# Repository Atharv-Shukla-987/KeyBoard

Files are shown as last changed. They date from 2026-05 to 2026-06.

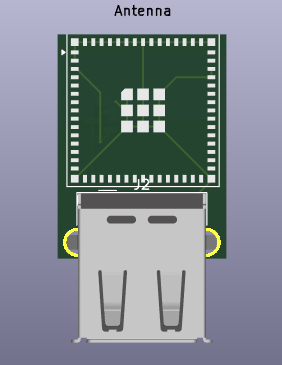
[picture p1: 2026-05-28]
img/reciever_3d_front.png

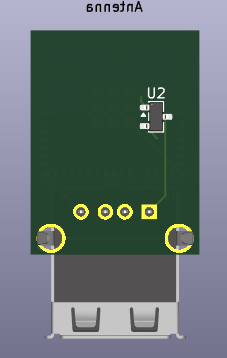
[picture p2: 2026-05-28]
img/reciever_3d_back.png

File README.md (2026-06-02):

# mech_board
## Introduction
It is compact wireless custum mechanical keyboard based on rasberry pi pico w with a 0.96 Oled display for displaying battery percentage and with a slider[linear potential meter] for music control and some DJ vibes, yes a slider not a rotary encoder because for some reason i just don't like rotary encoders. It has battery of 2000 mah . It can act as wired and wireless keyboard , both . I have a slider switch for changing the mode . It got two holes on its case wall one for charging port and other for pico port . I have also used RGBs for some asthetics. My pc does not have in built blutooth so , I have also made a reciever dougle.
## Components Used
### kerboard
 1.I have used raspberry pi pico w over others because beacause of high number of gpio pins and is easily programable and also is bluetooth and wifi for good contectivity
 2. A TP4050 [charging module] for charging battery
 
 3. A mcp1700 [voltage regulator] for converting 3.7v from battery to 5v requried from raspberry pi pico w
 
 4.A 1N4148 Diode so that ghosting do not occurs 

 5. A oled display 128x64 i2c for checking battery and making keyboard more intresting

 6. A SK6812 MINI for lightening and vibe

 7. A female Usb type C for charging 

 8. A 3.7V 2000mah lipo battery for increased battery life

 9. keycaps from meckeys

 10. custum pcb
 
 11. 3d printed case
 
 12. cherry x switches
 
 13. Capacitors and registors 

### reciever 

1.esp32 mini s3 for conecting with keyboard 

2. USb type A

3. MCP1700 voltage regulator

# RECIEVER

## schematics



## PCB layout

reciever_pcb

## 3d

### Front



### Back



# KEYBOARD

## schematic

keyboard_schematics

## PCB layout

keyboard_pcb_layout

## 3D 
### front



### back Model



## footprints







## Case

### Top case

Case_top

### Bottom case

Case_bottom

### Assembled case

Assembly

# BOM 

https://docs.google.com/spreadsheets/d/1NN-7fyjT-_NMtKUpMZtBps8UBcZRbg7seoi4lXChdCc/edit?usp=sharing


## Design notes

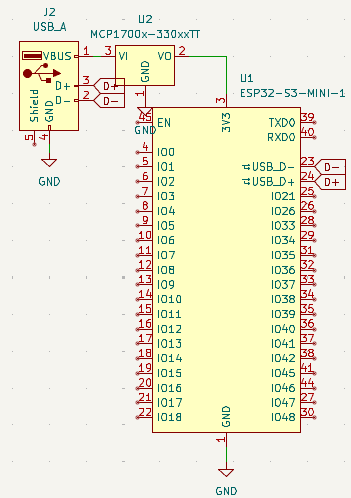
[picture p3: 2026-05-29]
img/reciever_schematics.png

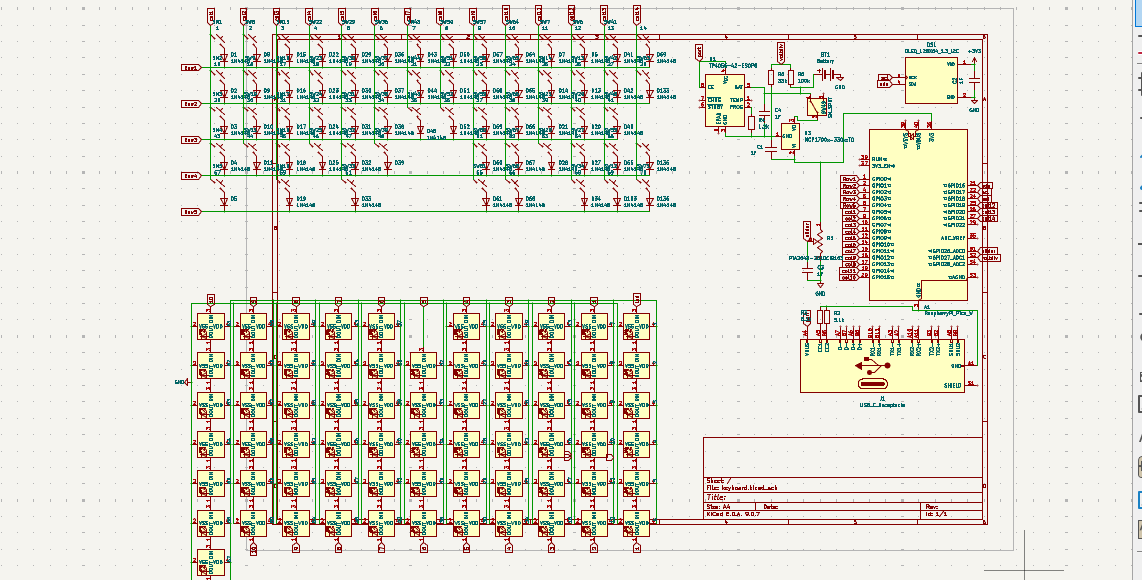
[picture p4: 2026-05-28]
img/keyboard_schematics.png

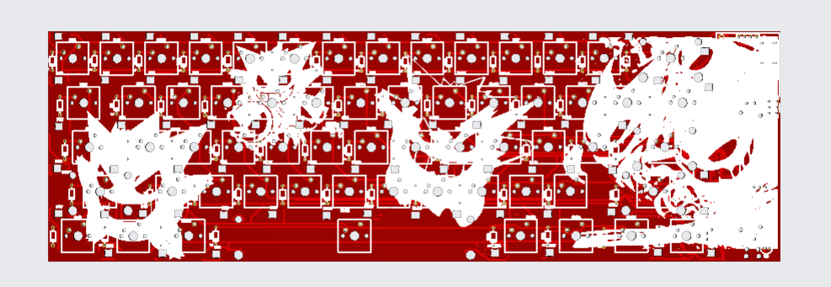
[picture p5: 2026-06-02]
img/keyboard_3d_front.png

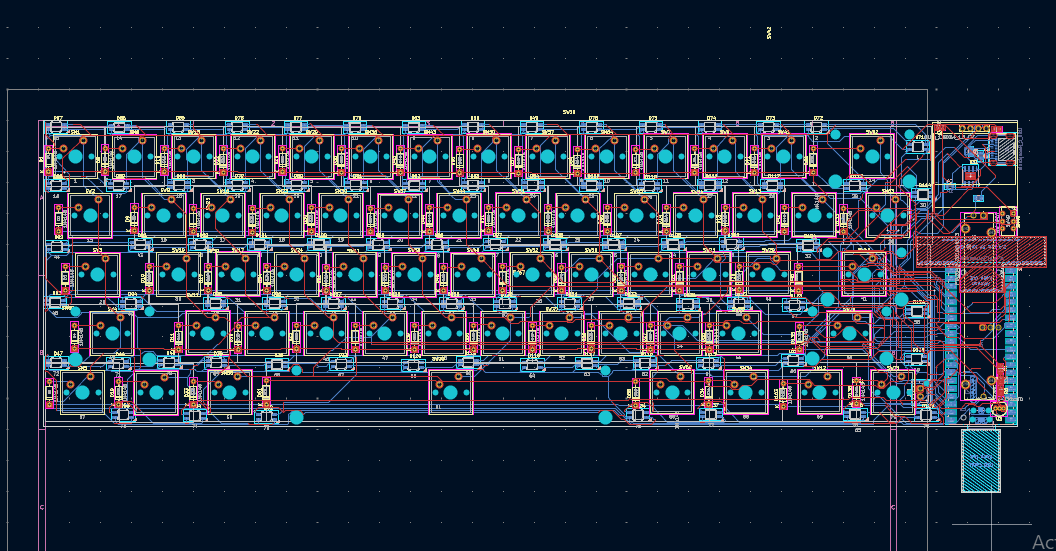
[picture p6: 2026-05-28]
img/keyboard_pcb_layout.png

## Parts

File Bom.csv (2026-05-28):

Item | Quantity | Cost per piece | Total Cost ( IN INR) | Cost in Usd( 1usd =95.23) | link
1N4148 Diode | 100 | 2 rupees | 200 | 2.1 usd | https://www.amazon.in/Embeddinator-1N4148-Diode-Pack-50/dp/B0B53NV1QC
SK6812 MINI | 200 |  | 1423 | 15usd | https://www.desertcart.in/products/792826292-200pcs-sk6812-mini-e-rgb-similar-ws2812b-sk6812-3228-smd
Rasberrypi pico w + RESISTORS (100K,33K,1.2K,5.1L) | 1 | 900 | ₹869.07 | 9 usd | https://photos.app.goo.gl/kQwkpoZnvVd7d1E5A
Battery 3.7 V | 1 | 1 | 200 | 2.1 usd | https://roboman.in/product/704060-3-7v-2000mah-lipo-battery-rechargeable-lithium-polymer-battery-with-bms/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
tp4056 | 1 | 40 | 40 | 0.5 usd | https://evelta.com/tp4056x-42-esop8-lithium-ion-battery-management-1a-ic-sop-8-ep/?sku=129-TP4056X-42-ESOP8
mcp1700 | 1 | 60 | 60 | 0.64usd | https://robu.in/product/mcp1700-3302e-to-microchip-fixed-ldo-voltage-regulator-2-3v-to-6v-to-92-3/
Akko Creamy Cyan Switch (Pack of 45) | 2 | 1299 | 2598 | 27.3 usd | https://stackskb.com/store/akko-creamy-cyan-switch-pack-of-45-pre-order/
esp32 mini s3 | 1 | 242 | 404 | 4.2 USD | https://www.lioncircuits.com/parts/ESP32-C3-MINI-1-N4-A
usb type A male ( pack of 10) | 1 | 130 | 130 | 1.36 usd | https://www.amazon.in/ICSTORE-4-Pin-Solder-Connector-Degree/dp/B0BQ7JFZDF/521-4557262-6496425
usb type C female ( pack of 5) | 1 | 100 | 100 | 1.05 USD | https://www.amazon.in/UNIVERSAL-HUB-Type-C-Connector-Breakout/dp/B0DYJMNZM1
oled display 128x64 i2c | 1 | 315 | 315 | 3.3 usd | https://www.amazon.in/IDUINO-SSD1306-Self-Luminous-Display-Raspberry/dp/B0BNWC7X54
capacitor 1 uf(pack of 10) | 1 | 99 | 99 | 1.05 usd | https://www.amazon.in/AVS-COMPONENTS-Aluminium-Electrolytic-Capacitor/dp/B08P5JX8YK?s=industrial
keycaps | 1 | 1399 | 1399 | 14.7 Usd | https://meckeys.com/shop/accessories/keyboard-accessories/keycaps/gengar-anime-keycap-set/
pcb | 5 | 800 | 5000 | 52.5usd
4mm SPDT 1P2T Slide Switch – PCB Mount Switch |  |  |  |  | https://techtonics.in/product/4mm-spdt-1p2t-slide-switch-pack-of-10/
slider [ liner potentialmeter] | 1 | 128 | 218 | 2.29usd | https://robomart.com/product/pta4543-2015dpb103-bourns/
3d printing |  |  | 300 | 3.16usd
stablizer set(4+1) | 1 | 1098 | 1098 | 11.6usd | https://www.keebsmod.com/products/cherry-clip-in-stabilizers?variant=50380987007274&country=IN&currency=INR
total |  |  | 14453 | 152.5 usd

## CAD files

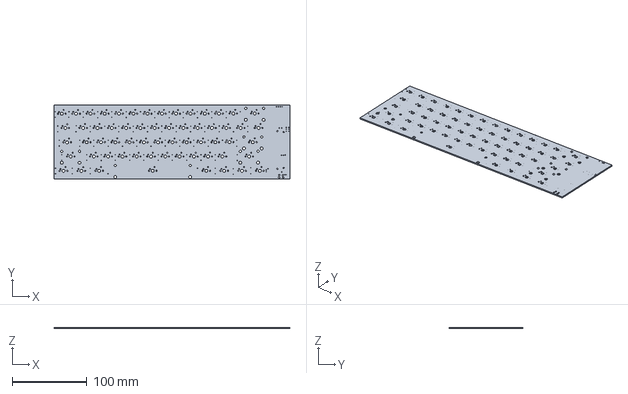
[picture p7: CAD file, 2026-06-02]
cad/keyboard_pcb.step
314.8 x 99.0 x 1.60 mm

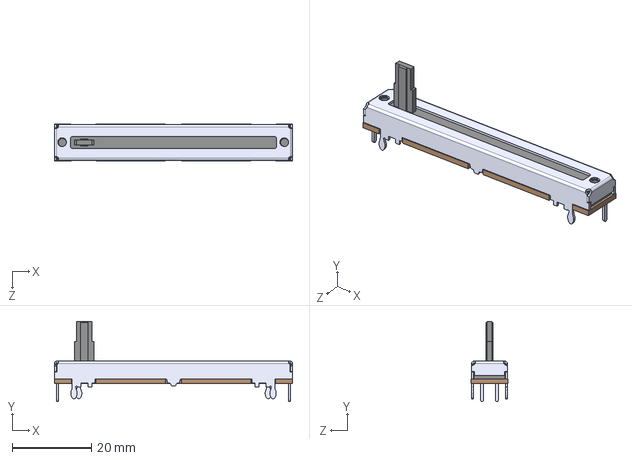
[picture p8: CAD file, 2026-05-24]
PTA4543-2010CPB103/PTA4543-2010CPB103.step
60.0 x 20.2 x 9.40 mm

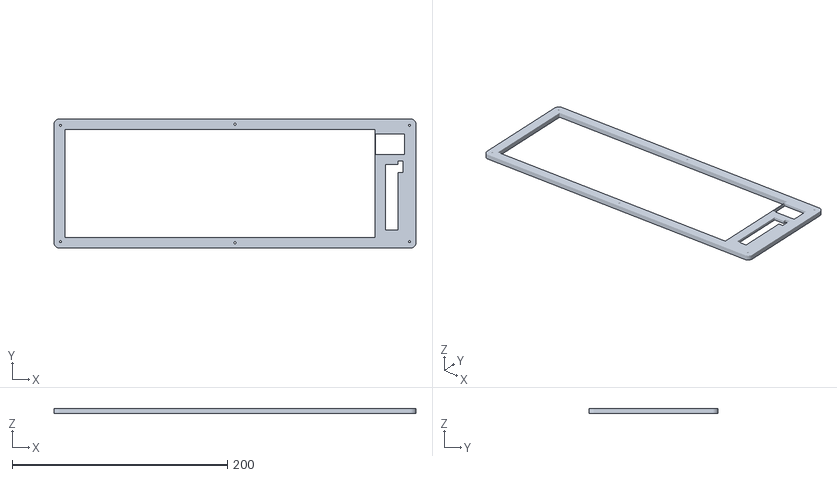
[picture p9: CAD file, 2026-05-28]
cad/keeb_top.stl
336.0 x 120.0 x 5.00

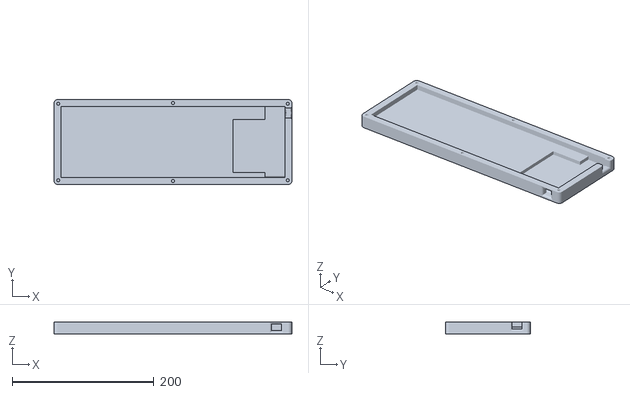
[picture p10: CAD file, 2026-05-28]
cad/keeb_bottom.stl
336.0 x 120.0 x 17.0

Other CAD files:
cad/keeb_bottom.f3z
cad/keeb_top.f3d

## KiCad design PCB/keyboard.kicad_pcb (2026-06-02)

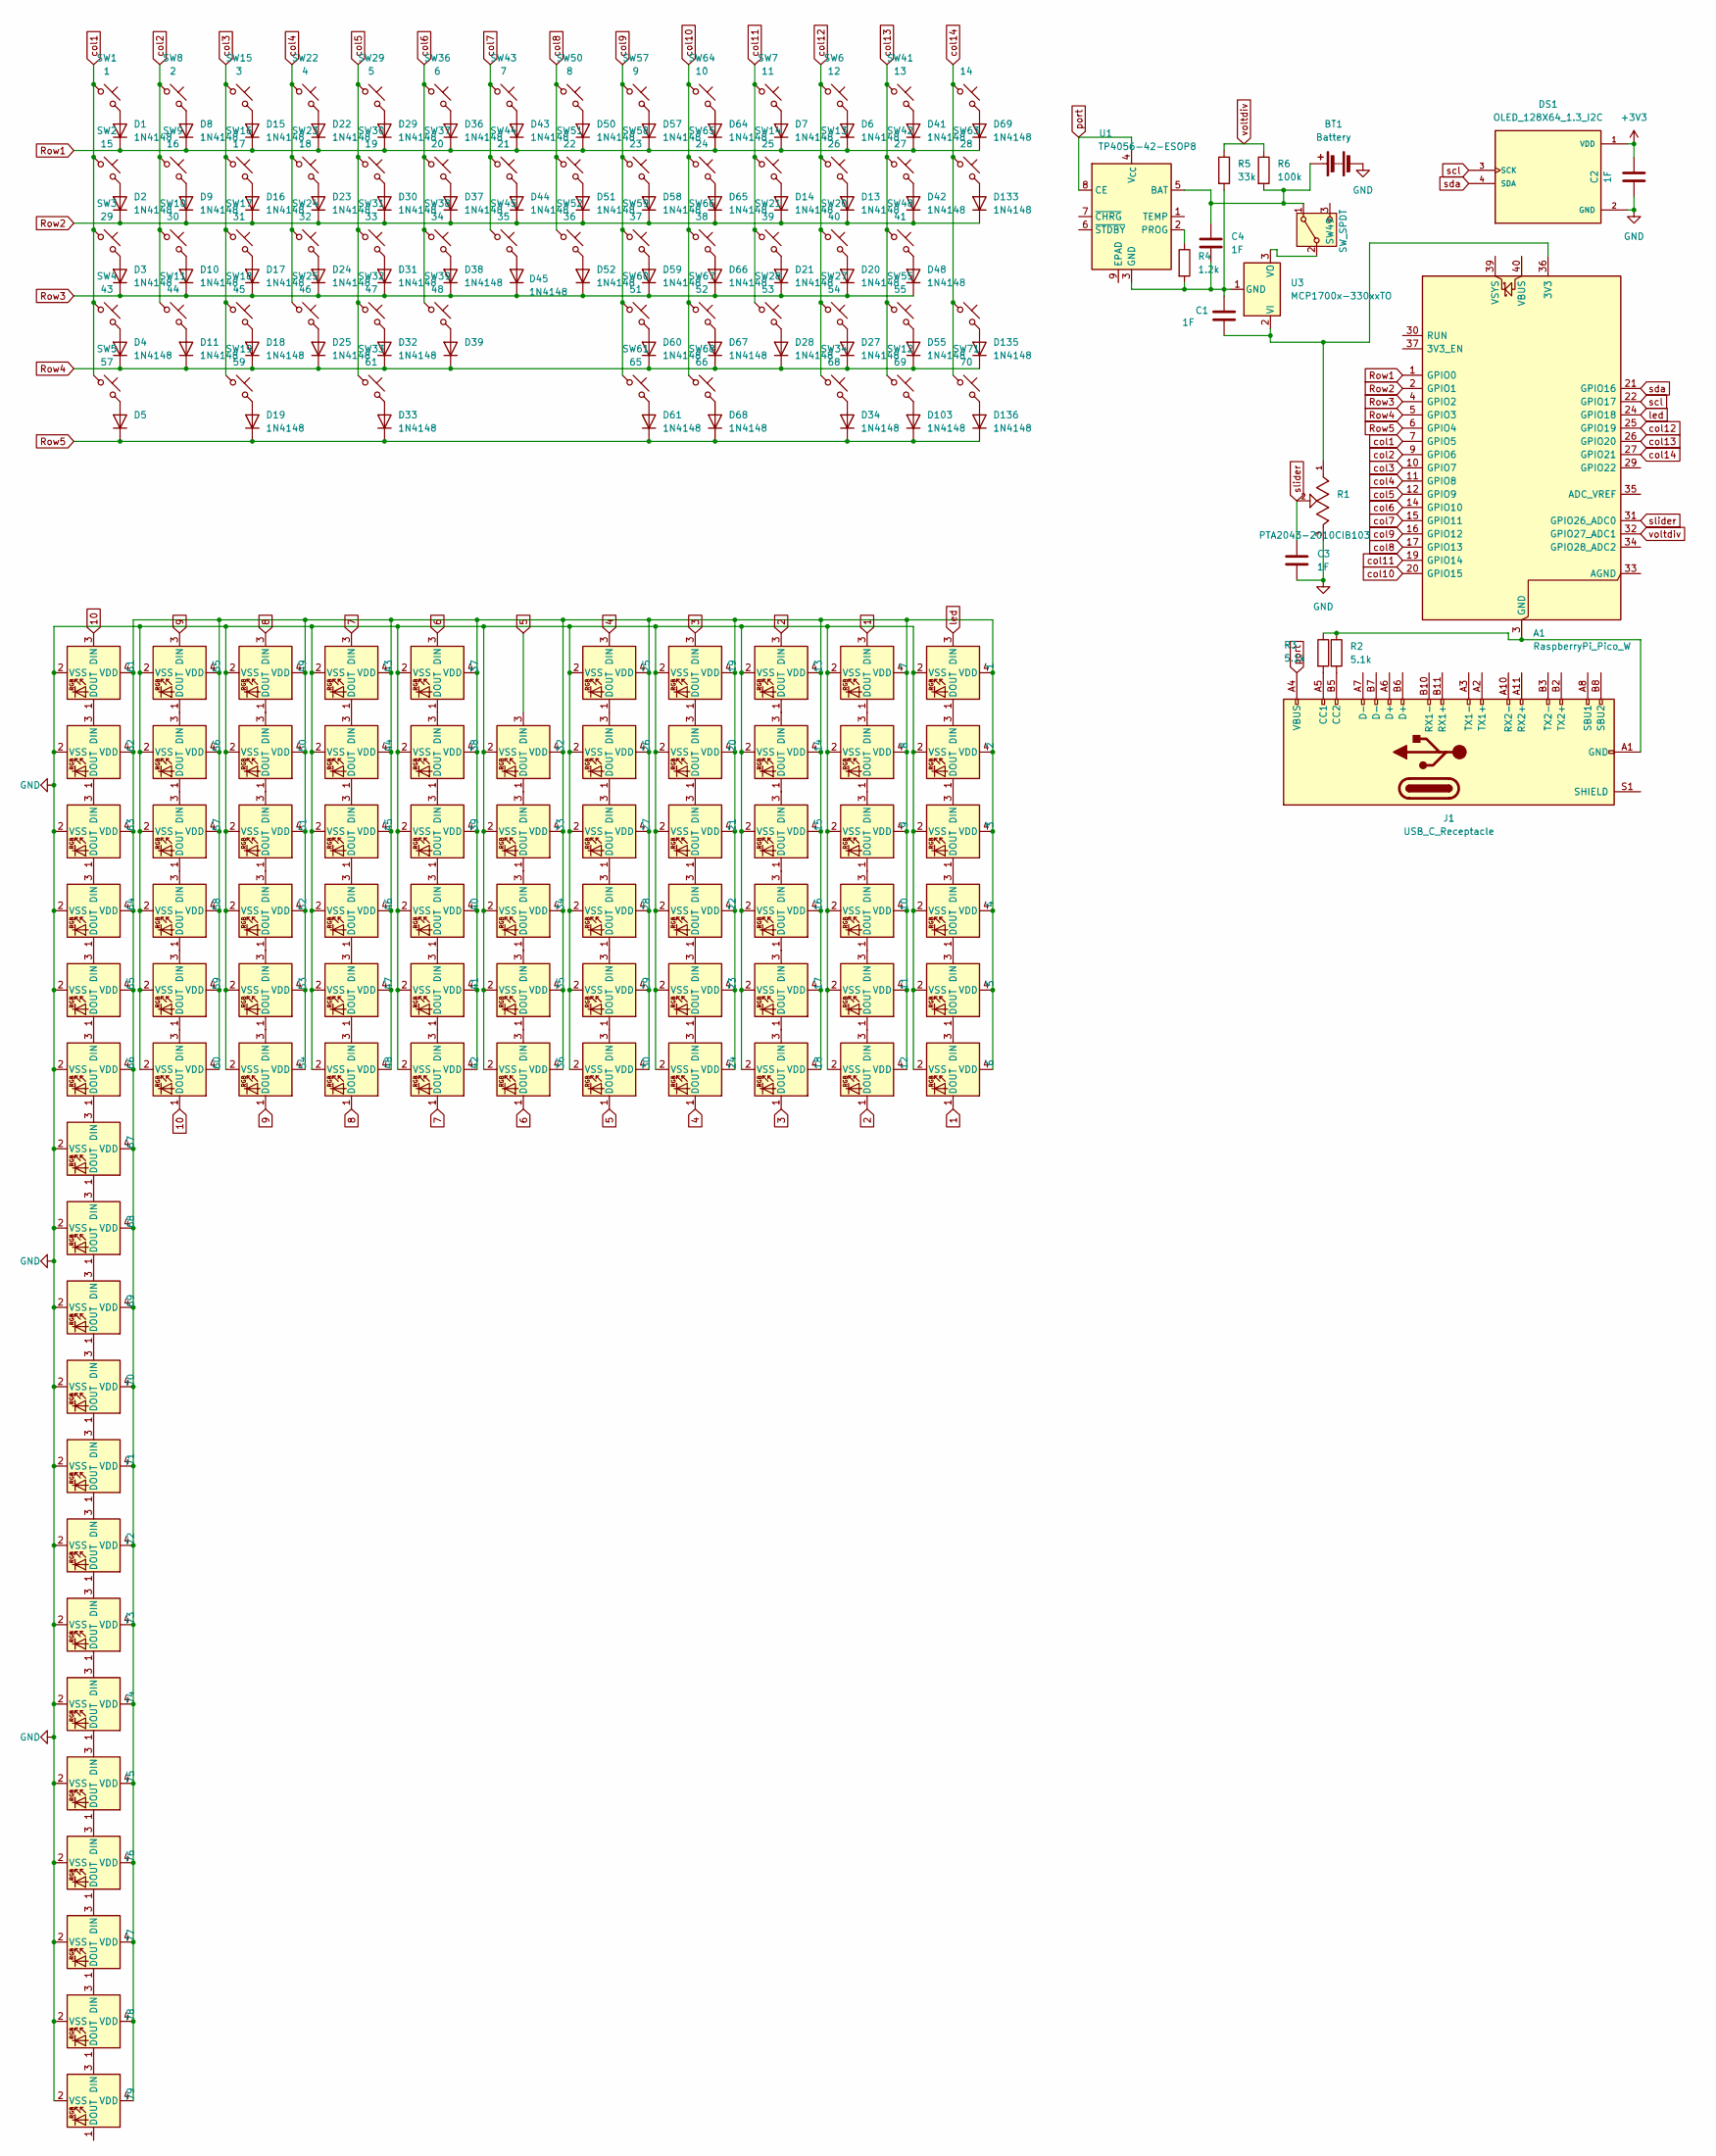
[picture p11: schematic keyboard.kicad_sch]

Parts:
A1: RaspberryPi_Pico_W; RaspberryPi_Pico_W_SMD_HandSolder
BT1: Battery; JST_XH_B2B-XH-AM_1x02_P2.50mm_Vertical
C1, C2, C3, C4: 1F; C_0805_2012Metric
D1, D2, D3, D4, D5, D6, D7, D8, D9, D10, D11, D13, D14, D15, D16, D17, D18, D19, D20, D21, D22, D23, D24, D25, D27, D28, D29, D30, D31, D32, D33, D34, D36, D37, D38, D39, D41, D42, D43, D44, D45, D48, D50, D51, D52, D55, D57, D58, D59, D60, D61, D64, D65, D66, D67, D68, D69, D103, D133, D135, D136: 1N4148; D_DO-35_SOD27_P7.62mm_Horizontal
D12: 67; SK6812MINI-E_fixed
D26: 68; SK6812MINI-E_fixed
D35: 69; SK6812MINI-E_fixed
D40: 70; SK6812MINI-E_fixed
D46: 71; SK6812MINI-E_fixed
D47: 72; SK6812MINI-E_fixed
D49: 7; SK6812MINI-E_fixed
D53: 73; SK6812MINI-E_fixed
D54: 74; SK6812MINI-E_fixed
D56: 8; SK6812MINI-E_fixed
D62: 75; SK6812MINI-E_fixed
D63: 9; SK6812MINI-E_fixed
D70: 10; SK6812MINI-E_fixed
D71: 1; SK6812MINI-E_fixed
D72: 2; SK6812MINI-E_fixed
D73: 3; SK6812MINI-E_fixed
D74: 4; SK6812MINI-E_fixed
D75: 5; SK6812MINI-E_fixed
D76: 6; SK6812MINI-E_fixed
D77: 11; SK6812MINI-E_fixed
D78: 12; SK6812MINI-E_fixed
D79: 19; SK6812MINI-E_fixed
D80: 20; SK6812MINI-E_fixed
D81: 21; SK6812MINI-E_fixed
D82: 22; SK6812MINI-E_fixed
D83: 23; SK6812MINI-E_fixed
D84: 24; SK6812MINI-E_fixed
D85: 13; SK6812MINI-E_fixed
D86: 14; SK6812MINI-E_fixed
D87: 15; SK6812MINI-E_fixed
D88: 16; SK6812MINI-E_fixed
D89: 17; SK6812MINI-E_fixed
D90: 18; SK6812MINI-E_fixed
D91: 43; SK6812MINI-E_fixed
D92: 44; SK6812MINI-E_fixed
D93: 45; SK6812MINI-E_fixed
D94: 46; SK6812MINI-E_fixed
D95: 47; SK6812MINI-E_fixed
D96: 48; SK6812MINI-E_fixed
D97: 37; SK6812MINI-E_fixed
D98: 38; SK6812MINI-E_fixed
D99: 39; SK6812MINI-E_fixed
D100: 40; SK6812MINI-E_fixed
D101: 41; SK6812MINI-E_fixed
D102: 42; SK6812MINI-E_fixed
D104: 32; SK6812MINI-E_fixed
D105: 33; SK6812MINI-E_fixed
D106: 34; SK6812MINI-E_fixed
D107: 35; SK6812MINI-E_fixed
D108: 36; SK6812MINI-E_fixed
D109: 25; SK6812MINI-E_fixed
D110: 26; SK6812MINI-E_fixed
D111: 27; SK6812MINI-E_fixed
D112: 28; SK6812MINI-E_fixed
D113: 29; SK6812MINI-E_fixed
D114: 30; SK6812MINI-E_fixed
D115: 61; SK6812MINI-E_fixed
D116: 62; SK6812MINI-E_fixed
D117: 63; SK6812MINI-E_fixed
D118: 64; SK6812MINI-E_fixed
D119: 65; SK6812MINI-E_fixed
D120: 66; SK6812MINI-E_fixed
D121: 55; SK6812MINI-E_fixed
D122: 56; SK6812MINI-E_fixed
D123: 57; SK6812MINI-E_fixed
D124: 58; SK6812MINI-E_fixed
D125: 59; SK6812MINI-E_fixed
D126: 60; SK6812MINI-E_fixed
D127: 49; SK6812MINI-E_fixed
D128: 50; SK6812MINI-E_fixed
D129: 51; SK6812MINI-E_fixed
D130: 52; SK6812MINI-E_fixed
D131: 53; SK6812MINI-E_fixed
D132: 54; SK6812MINI-E_fixed
D134: 76; SK6812MINI-E_fixed
D137: 77; SK6812MINI-E_fixed
D138: 78; SK6812MINI-E_fixed
D139: 79; SK6812MINI-E_fixed
DS1: OLED_128X64_1.3_I2C; LCD_OLED_128X64_1.3_I2C; PARTREV NA
J1: USB_C_Receptacle; USB_C_Receptacle_Molex_105450-0101
R1: PTA2043-2010CIB103; TRIM_PTA4543-2010CPB103; PARTREV 04/21
R2, R3: 5.1k; R_0805_2012Metric
R4: 1.2k; R_0805_2012Metric
R5: 33k; R_0805_2012Metric
R6: 100k; R_0805_2012Metric
SW1: 1; SW_Cherry_MX1A_1.00u_PCB
SW2: 15; SW_Cherry_MX1A_1.50u_PCB
SW3: 29; SW_Cherry_MX1A_1.75u_PCB
SW4: 43; SW_Cherry_MX1A_2.25u_PCB
SW5: 57; SW_Cherry_MX1A_1.25u_PCB
SW6: 12; SW_Cherry_MX1A_1.00u_PCB
SW7: 11; SW_Cherry_MX1A_1.00u_PCB
SW8: 2; SW_Cherry_MX1A_1.00u_PCB
SW9: 16; SW_Cherry_MX1A_1.00u_PCB
SW10: 30; SW_Cherry_MX1A_1.00u_PCB
SW11: 44; SW_Cherry_MX1A_1.00u_PCB
SW12: 69; SW_Cherry_MX1A_1.25u_PCB
SW13: 26; SW_Cherry_MX1A_1.00u_PCB
SW14: 25; SW_Cherry_MX1A_1.00u_PCB
SW15: 3; SW_Cherry_MX1A_1.00u_PCB
SW16: 17; SW_Cherry_MX1A_1.00u_PCB
SW17: 31; SW_Cherry_MX1A_1.00u_PCB
SW18: 45; SW_Cherry_MX1A_1.00u_PCB
SW19: 59; SW_Cherry_MX1A_1.25u_PCB
SW20: 40; SW_Cherry_MX1A_1.00u_PCB
SW21: 39; SW_Cherry_MX1A_1.00u_PCB
SW22: 4; SW_Cherry_MX1A_1.00u_PCB
SW23: 18; SW_Cherry_MX1A_1.00u_PCB
SW24: 32; SW_Cherry_MX1A_1.00u_PCB
SW25: 46; SW_Cherry_MX1A_1.00u_PCB
SW27: 54; SW_Cherry_MX1A_1.00u_PCB
SW28: 53; SW_Cherry_MX1A_1.00u_PCB
SW29: 5; SW_Cherry_MX1A_1.00u_PCB
SW30: 19; SW_Cherry_MX1A_1.00u_PCB
SW31: 33; SW_Cherry_MX1A_1.00u_PCB
SW32: 47; SW_Cherry_MX1A_1.00u_PCB
SW33: 61; SW_Cherry_MX1A_1.25u_PCB
SW34: 68; SW_Cherry_MX1A_1.25u_PCB
SW36: 6; SW_Cherry_MX1A_1.00u_PCB
SW37: 20; SW_Cherry_MX1A_1.00u_PCB
SW38: 34; SW_Cherry_MX1A_1.00u_PCB
SW39: 48; SW_Cherry_MX1A_1.00u_PCB
SW41: 13; SW_Cherry_MX1A_1.00u_PCB
SW42: 27; SW_Cherry_MX1A_1.00u_PCB
SW43: 7; SW_Cherry_MX1A_1.00u_PCB
SW44: 21; SW_Cherry_MX1A_1.00u_PCB
SW45: 35; SW_Cherry_MX1A_1.00u_PCB
SW48: 41; SW_Cherry_MX1A_2.25u_PCB
SW49: SW_SPDT; SW_Slide_1P2T_CK_OS102011MS2Q
SW50: 8; SW_Cherry_MX1A_1.00u_PCB
SW51: 22; SW_Cherry_MX1A_1.00u_PCB
SW52: 36; SW_Cherry_MX1A_1.00u_PCB
SW55: 55; SW_Cherry_MX1A_1.00u_PCB
SW57: 9; SW_Cherry_MX1A_1.00u_PCB
SW58: 23; SW_Cherry_MX1A_1.00u_PCB
SW59: 37; SW_Cherry_MX1A_1.00u_PCB
SW60: 51; SW_Cherry_MX1A_1.00u_PCB
SW61: 65; SW_Cherry_MX1A_6.25u_PCB
SW62: 14; SW_Cherry_MX1A_2.00u_PCB
SW63: 28; SW_Cherry_MX1A_1.50u_PCB
SW64: 10; SW_Cherry_MX1A_1.00u_PCB
SW65: 24; SW_Cherry_MX1A_1.00u_PCB
SW66: 38; SW_Cherry_MX1A_1.00u_PCB
SW67: 52; SW_Cherry_MX1A_1.00u_PCB
SW68: 66; SW_Cherry_MX1A_1.25u_PCB
SW70: 56; SW_Cherry_MX1A_2.75u_PCB
SW71: 70; SW_Cherry_MX1A_1.25u_PCB
U1: TP4056-42-ESOP8; SOIC-8-1EP_3.9x4.9mm_P1.27mm_EP2.41x3.3mm_ThermalVias
U3: MCP1700x-330xxTO; TO-92_Inline

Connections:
1: D49.3 (DIN), D76.1 (DOUT)
2: D78.1 (DOUT), D85.3 (DIN)
3: D79.3 (DIN), D90.1 (DOUT)
4: D84.1 (DOUT), D109.3 (DIN)
5: D104.3 (DIN), D114.1 (DOUT)
6: D97.3 (DIN), D108.1 (DOUT)
7: D91.3 (DIN), D102.1 (DOUT)
8: D96.1 (DOUT), D127.3 (DIN)
9: D121.3 (DIN), D132.1 (DOUT)
10: D115.3 (DIN), D126.1 (DOUT)
+3V3: C2.1, DS1.1 (VDD)
<NO NET>: D12.4 (VDD), D26.4 (VDD), D35.4 (VDD), D40.4 (VDD), D46.4 (VDD), D47.4 (VDD), D49.4 (VDD), D53.4 (VDD), D54.4 (VDD), D56.4 (VDD), D62.4 (VDD), D63.4 (VDD), D70.4 (VDD), D71.4 (VDD), D72.4 (VDD), D73.4 (VDD), D74.4 (VDD), D75.4 (VDD), D76.4 (VDD), D77.4 (VDD), D78.4 (VDD), D79.4 (VDD), D80.4 (VDD), D81.4 (VDD), D82.4 (VDD), D83.4 (VDD), D84.4 (VDD), D85.4 (VDD), D86.4 (VDD), D87.4 (VDD), D88.4 (VDD), D89.4 (VDD), D90.4 (VDD), D91.4 (VDD), D92.4 (VDD), D93.4 (VDD), D94.4 (VDD), D95.4 (VDD), D96.4 (VDD), D97.4 (VDD), D98.4 (VDD), D99.4 (VDD), D100.4 (VDD), D101.4 (VDD), D102.4 (VDD), D104.4 (VDD), D105.4 (VDD), D106.4 (VDD), D107.4 (VDD), D108.4 (VDD), D109.4 (VDD), D110.4 (VDD), D111.4 (VDD), D112.4 (VDD), D113.4 (VDD), D114.4 (VDD), D115.4 (VDD), D116.4 (VDD), D117.4 (VDD), D118.4 (VDD), D119.4 (VDD), D120.4 (VDD), D121.4 (VDD), D122.4 (VDD), D123.4 (VDD), D124.4 (VDD), D125.4 (VDD), D126.4 (VDD), D127.4 (VDD), D128.4 (VDD), D129.4 (VDD), D130.4 (VDD), D131.4 (VDD), D132.4 (VDD), D134.4 (VDD), D137.4 (VDD), D138.4 (VDD), D139.4 (VDD)
GND: BT1.2 (-), C2.2, C3.2, D12.2 (VSS), D26.2 (VSS), D35.2 (VSS), D40.2 (VSS), D46.2 (VSS), D47.2 (VSS), D49.2 (VSS), D53.2 (VSS), D54.2 (VSS), D56.2 (VSS), D62.2 (VSS), D63.2 (VSS), D70.2 (VSS), D71.2 (VSS), D72.2 (VSS), D73.2 (VSS), D74.2 (VSS), D75.2 (VSS), D76.2 (VSS), D77.2 (VSS), D78.2 (VSS), D79.2 (VSS), D80.2 (VSS), D81.2 (VSS), D82.2 (VSS), D83.2 (VSS), D84.2 (VSS), D85.2 (VSS), D86.2 (VSS), D87.2 (VSS), D88.2 (VSS), D89.2 (VSS), D90.2 (VSS), D91.2 (VSS), D92.2 (VSS), D93.2 (VSS), D94.2 (VSS), D95.2 (VSS), D96.2 (VSS), D97.2 (VSS), D98.2 (VSS), D99.2 (VSS), D100.2 (VSS), D101.2 (VSS), D102.2 (VSS), D104.2 (VSS), D105.2 (VSS), D106.2 (VSS), D107.2 (VSS), D108.2 (VSS), D109.2 (VSS), D110.2 (VSS), D111.2 (VSS), D112.2 (VSS), D113.2 (VSS), D114.2 (VSS), D115.2 (VSS), D116.2 (VSS), D117.2 (VSS), D118.2 (VSS), D119.2 (VSS), D120.2 (VSS), D121.2 (VSS), D122.2 (VSS), D123.2 (VSS), D124.2 (VSS), D125.2 (VSS), D126.2 (VSS), D127.2 (VSS), D128.2 (VSS), D129.2 (VSS), D130.2 (VSS), D131.2 (VSS), D132.2 (VSS), D134.2 (VSS), D137.2 (VSS), D138.2 (VSS), D139.2 (VSS), DS1.2 (GND), R1.3
unnamed: A1.36 (3V3), C1.2, R1.1, U3.2 (VI)
unnamed: A1.3 (GND), A1.8 (GND), A1.13 (GND), A1.18 (GND), A1.23 (GND), A1.28 (GND), A1.38 (GND), J1.A1 (GND), J1.A12 (GND), J1.B1 (GND), J1.B12 (GND), R2.1, R3.1
unnamed: BT1.1 (+), C4.1, R6.2, SW49.1 (A), U1.5 (BAT)
unnamed: D1.2 (A), SW1.2
unnamed: D2.2 (A), SW2.2
unnamed: D3.2 (A), SW3.2
unnamed: D4.2 (A), SW4.2
unnamed: D5.2 (A), SW5.2
unnamed: D6.2 (A), SW6.2
unnamed: D7.2 (A), SW7.2
unnamed: D8.2 (A), SW8.2
unnamed: D9.2 (A), SW9.2
unnamed: D10.2 (A), SW10.2
unnamed: D11.2 (A), SW11.2
unnamed: D12.3 (DIN), D120.1 (DOUT)
unnamed: D12.1 (DOUT), D26.3 (DIN)
unnamed: D13.2 (A), SW13.2
unnamed: D14.2 (A), SW14.2
unnamed: D15.2 (A), SW15.2
unnamed: D16.2 (A), SW16.2
unnamed: D17.2 (A), SW17.2
unnamed: D18.2 (A), SW18.2
unnamed: D19.2 (A), SW19.2
unnamed: D20.2 (A), SW20.2
unnamed: D21.2 (A), SW21.2
unnamed: D22.2 (A), SW22.2
unnamed: D23.2 (A), SW23.2
unnamed: D24.2 (A), SW24.2
unnamed: D25.2 (A), SW25.2
unnamed: D26.1 (DOUT), D35.3 (DIN)
unnamed: D27.2 (A), SW27.2
unnamed: D28.2 (A), SW28.2
unnamed: D29.2 (A), SW29.2
unnamed: D30.2 (A), SW30.2
unnamed: D31.2 (A), SW31.2
unnamed: D32.2 (A), SW32.2
unnamed: D33.2 (A), SW33.2
unnamed: D34.2 (A), SW34.2
unnamed: D35.1 (DOUT), D40.3 (DIN)
unnamed: D36.2 (A), SW36.2
unnamed: D37.2 (A), SW37.2
unnamed: D38.2 (A), SW38.2
unnamed: D39.2 (A), SW39.2
unnamed: D40.1 (DOUT), D46.3 (DIN)
unnamed: D41.2 (A), SW41.2
unnamed: D42.2 (A), SW42.2
unnamed: D43.2 (A), SW43.2
unnamed: D44.2 (A), SW44.2
unnamed: D45.2 (A), SW45.2
unnamed: D46.1 (DOUT), D47.3 (DIN)
unnamed: D47.1 (DOUT), D53.3 (DIN)
unnamed: D48.2 (A), SW48.2
unnamed: D49.1 (DOUT), D56.3 (DIN)
unnamed: D50.2 (A), SW50.2
unnamed: D51.2 (A), SW51.2
unnamed: D52.2 (A), SW52.2
unnamed: D53.1 (DOUT), D54.3 (DIN)
unnamed: D54.1 (DOUT), D62.3 (DIN)
unnamed: D55.2 (A), SW55.2
unnamed: D56.1 (DOUT), D63.3 (DIN)
unnamed: D57.2 (A), SW57.2
unnamed: D58.2 (A), SW58.2
unnamed: D59.2 (A), SW59.2
unnamed: D60.2 (A), SW60.2
unnamed: D61.2 (A), SW61.2
unnamed: D63.1 (DOUT), D70.3 (DIN)
unnamed: D64.2 (A), SW64.2
unnamed: D65.2 (A), SW65.2
unnamed: D66.2 (A), SW66.2
unnamed: D67.2 (A), SW67.2
unnamed: D68.2 (A), SW68.2
unnamed: D69.2 (A), SW62.2
unnamed: D70.1 (DOUT), D77.3 (DIN)
unnamed: D71.1 (DOUT), D72.3 (DIN)
unnamed: D72.1 (DOUT), D73.3 (DIN)
unnamed: D73.1 (DOUT), D74.3 (DIN)
unnamed: D74.1 (DOUT), D75.3 (DIN)
unnamed: D75.1 (DOUT), D76.3 (DIN)
unnamed: D77.1 (DOUT), D78.3 (DIN)
unnamed: D79.1 (DOUT), D80.3 (DIN)
unnamed: D80.1 (DOUT), D81.3 (DIN)
unnamed: D81.1 (DOUT), D82.3 (DIN)
unnamed: D82.1 (DOUT), D83.3 (DIN)
unnamed: D83.1 (DOUT), D84.3 (DIN)
unnamed: D85.1 (DOUT), D86.3 (DIN)
unnamed: D86.1 (DOUT), D87.3 (DIN)
unnamed: D87.1 (DOUT), D88.3 (DIN)
unnamed: D88.1 (DOUT), D89.3 (DIN)
unnamed: D89.1 (DOUT), D90.3 (DIN)
unnamed: D91.1 (DOUT), D92.3 (DIN)
unnamed: D92.1 (DOUT), D93.3 (DIN)
unnamed: D93.1 (DOUT), D94.3 (DIN)
unnamed: D94.1 (DOUT), D95.3 (DIN)
unnamed: D95.1 (DOUT), D96.3 (DIN)
unnamed: D97.1 (DOUT), D98.3 (DIN)
unnamed: D98.1 (DOUT), D99.3 (DIN)
unnamed: D99.1 (DOUT), D100.3 (DIN)
unnamed: D100.1 (DOUT), D101.3 (DIN)
unnamed: D101.1 (DOUT), D102.3 (DIN)
unnamed: D103.2 (A), SW12.2
unnamed: D104.1 (DOUT), D105.3 (DIN)
unnamed: D105.1 (DOUT), D106.3 (DIN)
unnamed: D106.1 (DOUT), D107.3 (DIN)
unnamed: D107.1 (DOUT), D108.3 (DIN)
unnamed: D109.1 (DOUT), D110.3 (DIN)
unnamed: D110.1 (DOUT), D111.3 (DIN)
unnamed: D111.1 (DOUT), D112.3 (DIN)
unnamed: D112.1 (DOUT), D113.3 (DIN)
unnamed: D113.1 (DOUT), D114.3 (DIN)
unnamed: D115.1 (DOUT), D116.3 (DIN)
unnamed: D116.1 (DOUT), D117.3 (DIN)
unnamed: D117.1 (DOUT), D118.3 (DIN)
unnamed: D118.1 (DOUT), D119.3 (DIN)
unnamed: D119.1 (DOUT), D120.3 (DIN)
unnamed: D121.1 (DOUT), D122.3 (DIN)
unnamed: D122.1 (DOUT), D123.3 (DIN)
unnamed: D123.1 (DOUT), D124.3 (DIN)
unnamed: D124.1 (DOUT), D125.3 (DIN)
unnamed: D125.1 (DOUT), D126.3 (DIN)
unnamed: D127.1 (DOUT), D128.3 (DIN)
unnamed: D128.1 (DOUT), D129.3 (DIN)
unnamed: D129.1 (DOUT), D130.3 (DIN)
unnamed: D130.1 (DOUT), D131.3 (DIN)
unnamed: D131.1 (DOUT), D132.3 (DIN)
unnamed: D133.2 (A), SW63.2
unnamed: D62.1 (DOUT), D134.3 (DIN)
unnamed: D134.1 (DOUT), D137.3 (DIN)
unnamed: D135.2 (A), SW70.2
unnamed: D136.2 (A), SW71.2
unnamed: D137.1 (DOUT), D138.3 (DIN)
unnamed: D138.1 (DOUT), D139.3 (DIN)
unnamed: J1.A5 (CC1), R3.2
unnamed: J1.B5 (CC2), R2.2
unnamed: SW49.2 (B), U3.3 (VO)
unnamed: C1.1, C4.2, R4.2, R5.2, U1.3 (GND), U3.1 (GND)
unnamed: R4.1, U1.2 (PROG)
Row1: A1.1 (GPIO0), D1.1 (K), D6.1 (K), D7.1 (K), D8.1 (K), D15.1 (K), D22.1 (K), D29.1 (K), D36.1 (K), D41.1 (K), D43.1 (K), D50.1 (K), D57.1 (K), D64.1 (K), D69.1 (K)
Row2: A1.2 (GPIO1), D2.1 (K), D9.1 (K), D13.1 (K), D14.1 (K), D16.1 (K), D23.1 (K), D30.1 (K), D37.1 (K), D42.1 (K), D44.1 (K), D51.1 (K), D58.1 (K), D65.1 (K), D133.1 (K)
Row3: A1.4 (GPIO2), D3.1 (K), D10.1 (K), D17.1 (K), D20.1 (K), D21.1 (K), D24.1 (K), D31.1 (K), D38.1 (K), D45.1 (K), D48.1 (K), D52.1 (K), D59.1 (K), D66.1 (K)
Row4: A1.5 (GPIO3), D4.1 (K), D11.1 (K), D18.1 (K), D25.1 (K), D27.1 (K), D28.1 (K), D32.1 (K), D39.1 (K), D55.1 (K), D60.1 (K), D67.1 (K), D135.1 (K)
Row5: A1.6 (GPIO4), D5.1 (K), D19.1 (K), D33.1 (K), D34.1 (K), D61.1 (K), D68.1 (K), D103.1 (K), D136.1 (K)
col1: A1.7 (GPIO5), SW1.1, SW2.1, SW3.1, SW4.1, SW5.1
col2: A1.9 (GPIO6), SW8.1, SW9.1, SW10.1, SW11.1
col3: A1.10 (GPIO7), SW15.1, SW16.1, SW17.1, SW18.1, SW19.1
col4: A1.11 (GPIO8), SW22.1, SW23.1, SW24.1, SW25.1
col5: A1.12 (GPIO9), SW29.1, SW30.1, SW31.1, SW32.1, SW33.1
col6: A1.14 (GPIO10), SW36.1, SW37.1, SW38.1, SW39.1
col7: A1.15 (GPIO11), SW43.1, SW44.1, SW45.1
col8: A1.17 (GPIO13), SW50.1, SW51.1, SW52.1
col9: A1.16 (GPIO12), SW57.1, SW58.1, SW59.1, SW60.1, SW61.1
col10: A1.20 (GPIO15), SW64.1, SW65.1, SW66.1, SW67.1, SW68.1
col11: A1.19 (GPIO14), SW7.1, SW14.1, SW21.1, SW28.1
col12: A1.25 (GPIO19), SW6.1, SW13.1, SW20.1, SW27.1, SW34.1
col13: A1.26 (GPIO20), SW12.1, SW41.1, SW42.1, SW48.1, SW55.1
col14: A1.27 (GPIO21), SW62.1, SW63.1, SW70.1, SW71.1
led: A1.24 (GPIO18), D71.3 (DIN)
port: J1.A4 (VBUS), J1.A9 (VBUS), J1.B4 (VBUS), J1.B9 (VBUS), U1.4 (V_{CC}), U1.8 (CE)
scl: A1.22 (GPIO17), DS1.3 (SCK)
sda: A1.21 (GPIO16), DS1.4 (SDA)
slider: A1.31 (GPIO26_ADC0), C3.1, R1.2
voltdiv: A1.32 (GPIO27_ADC1), R5.1, R6.1

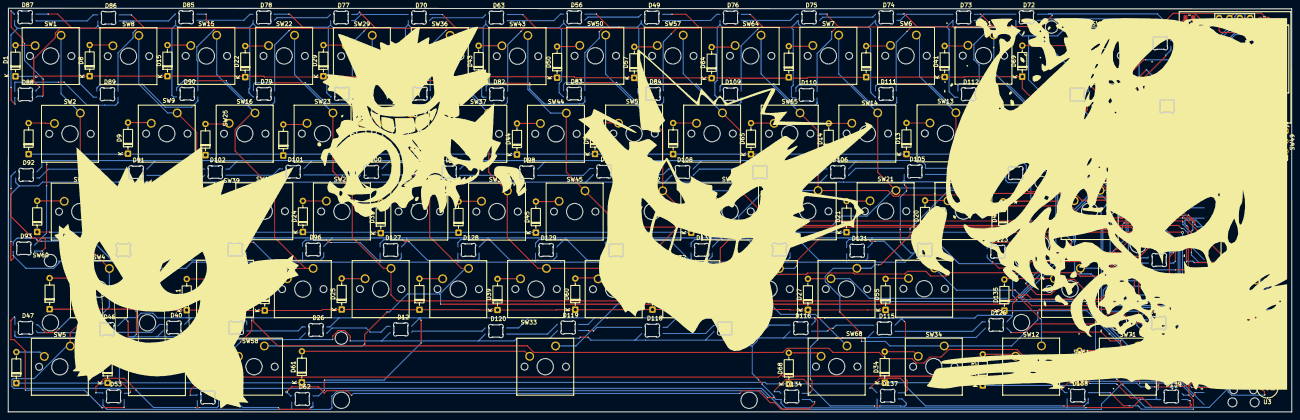
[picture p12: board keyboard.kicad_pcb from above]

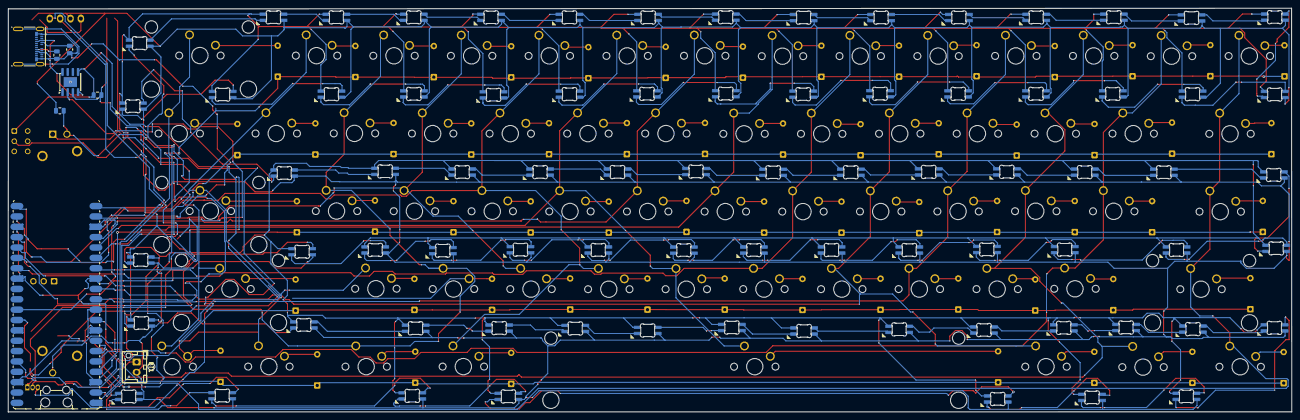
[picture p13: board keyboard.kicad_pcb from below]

Board: 2 copper layers, 314.8 x 99.0 mm, 217 parts (8 on the bottom side), 174 nets.

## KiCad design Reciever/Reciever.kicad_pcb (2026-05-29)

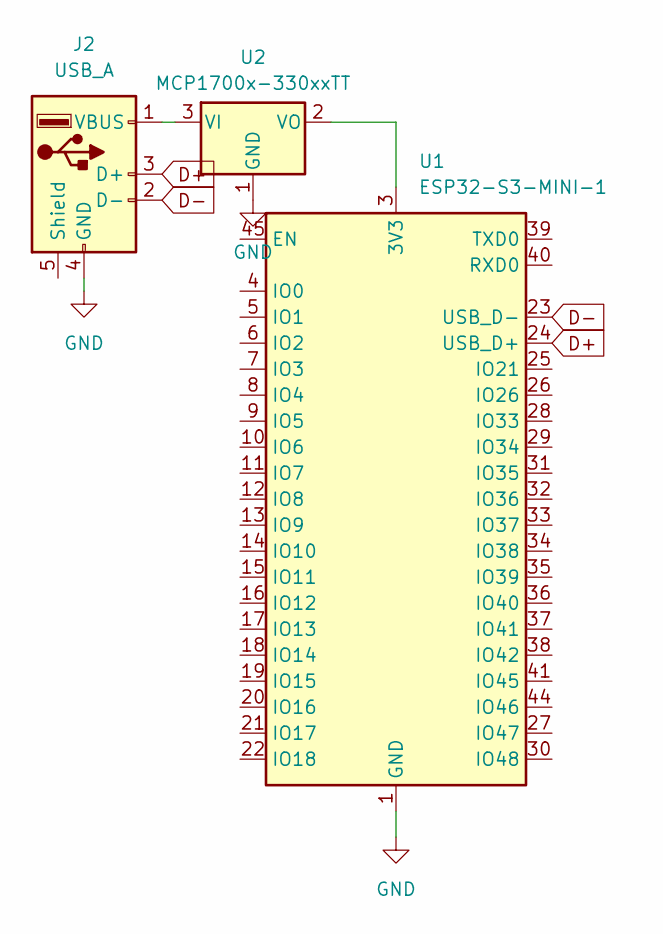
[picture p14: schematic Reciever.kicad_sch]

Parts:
J2: USB_A; USB_A_Molex_67643_Horizontal
U1: ESP32-S3-MINI-1; ESP32-S2-MINI-1
U2: MCP1700x-330xxTT; SOT-23

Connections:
D+: J2.3 (D+), U1.24 (USB_D+)
D-: J2.2 (D-), U1.23 (USB_D-)
GND: J2.4 (GND), U1.1 (GND), U1.2 (GND), U1.42 (GND), U1.43 (GND), U1.46 (GND), U1.47 (GND), U1.48 (GND), U1.49 (GND), U1.50 (GND), U1.51 (GND), U1.52 (GND), U1.53 (GND), U1.54 (GND), U1.55 (GND), U1.56 (GND), U1.57 (GND), U1.58 (GND), U1.59 (GND), U1.60 (GND), U1.61 (GND), U1.62 (GND), U1.63 (GND), U1.64 (GND), U1.65 (GND), U2.1 (GND)
unnamed: J2.1 (VBUS), U2.3 (VI)
unnamed: U1.3 (3V3), U2.2 (VO)

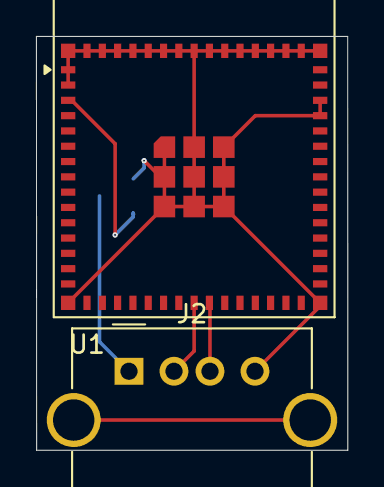
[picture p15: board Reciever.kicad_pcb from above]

Board: 2 copper layers, 17.3 x 23.0 mm, 3 parts (1 on the bottom side), 5 nets.

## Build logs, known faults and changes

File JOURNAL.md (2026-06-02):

# Creating Schematics  

It was the first step and the most important because I need to think what I want to make. I decided to make a 60% keyboard with linear slider for volume and a oled display for showing battery percentage , current mode(wifi/usd) , and current rgb setting  yes you are right it is a wireless keyboard with battery. I can use it in both way wired and wireless . I have used rasberrypi pico w , before it I was using ardiuno nano esp32 but it has not enough gpio pins so I decided to switch. As it runs on battery , for charging the battery I need a type c female port but it has 5v as output so I add MCP1700 voltage regulator and a charging module. I also add diodes to prevent ghosting and added leds for good looks. I have also done the decoupling . But i dont know how the battery percentage is calulated so I asked on slack and do some research about it finding about voltage divider so i used it. It was a long process as I am new to electronics . doing many mistakes and learning new things . But the it was not finished soon I realise my pc does not have in built blutooth so now i need to design a reciever. It was easy compared to previous work , I just use a esp32 mini s3 n4 chip for blutooth and a type A male port with a same MCP1700 voltage regulator.





  **Total time spent: 5 hours**

# Finding footprint 

I didn't thought it would took me soo long just to find right footprint. The most difficult footprint to find was of my linear slider because almost everyone uses rotary encoders . But I really want to use it . I was able to find only one footprint for it , I am still not satisfied by it but I can't do anything . I tried everywhere. I request to all of you who are reading this , if you find any such footprint please inform me.Other than i have used many wrong footprint which were later changed by me. it was the step where I size my switchs.



**Total time spent: 2 hours**

# PCB desiging 

Now , it was the time to create actual pcb . My aim was to make it as compact as possible, so it wont take too much space on my desk and is easy to carry. I placed rasberry pi pico on the right side beneath the pcb so I can fully utilize the area by placing linear slider on top. I did he same with oled display and charging port. I placed the display on top of pcb and charging port beneath the pcb . It was difficult to trace on the right side as there is the brain of my keyboard , pico w . As you can see in the image . There was some part in this area on  which I cannot trace , it is because there was no trace area . If I trace there than it can act as faraday cage blocking the communication signal of pico w . This make it extremely difficult as trace on right bottom cant go directly to right top , they must have to make a long route.



**Total time spent: 7 hours**

# Making the case 

I made the whole case in two part , top case and bottom case. Bottom case is the main body of the case. Its base is of 5mm and the wall are of 1cm ( first I made it of 5 mm too but while placing the screw , I thought it is good to use 1cm). It has 1cm deep hollow space for components beneath the pcb such as pico w , charging port and the battery . It also has hole for charging port and pico w port in walls. The top case is just a plate on non-switch region with wall of case . Its height is 5mm and the height of plate is 3mm . creating the top case was difficult than the bottom one , it is because ,sometimes the actual size of components is different from the footprint which conffused me. So I leave some margin . After it I offset the edges. Also I placed screw hole so I can assemble it . 

Case_bottom
Case_top
Assembly

**Total time spent: 4 hours**

# Changing the PCB layout 

I do that because I have used wrong footprint for led so when I changed it to correct one it show so many errors . It  was because correct has holes and is reverse mount . So almost every led trace came on hole or edge.cut .Not only that , my switch layout was custom so I was unable to find right keycap set and I am not great at all in CAD so I cant design them and buying every keycap separately makes it expensive. Thus  I decided to change switch size , changing the layout to a standard one so I had to retrace almost everything. It was same as making it again.

keyboard_pcb_layout

**Total time spent: 6 hours**

# Making the Bom and organising github repository 

making bom was one of easiest yet tiring part of this project , which was mainly due to my part selection , as i tried to reduce the overall cost of the project but whenever i found a cheaper option then its shipping charges were more than its actual value . and the most time consuming part was finding slider in budget as it the slider is not used much making it harder to find in exect size ....    

bom

**Total time spent: 5.5 hours**

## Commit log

2026-05-29 UPDATING RECIEVER
    [Reciever.kicad_pcb, Reciever.kicad_sch]
2026-06-02 Add new schematic image to README
    Added a new schematic image for the receiver section.
2026-06-02 Update README with new images for schematics and PCB
    Added additional schematic and PCB layout images for the keyboard.
2026-06-02 Document BOM creation and part selection challenges
    Added details about the BOM creation process and challenges faced during part selection.
2026-06-02 Update JOURNAL.md with project time and PCB design details
    Added total time spent on the project and detailed PCB design process.
